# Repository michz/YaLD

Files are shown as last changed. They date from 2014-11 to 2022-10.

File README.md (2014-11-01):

YaLD - Yet another LED driver
=============================

32 channel PWM driver, controlled by a AVR microcontroller,
controllable by DMX or IR remote.

DMX data port
-------------
The RJ45 connector for DMX data follows the ANSI E1.27-2 standard:
1: DMX+
2: DMX-
3: n.c.
4: n.c.
5: n.c.
6: n.c.
7: GND
8: GND

(This port *is not* compatible to Traxon/e:cue DMX interfaces.)

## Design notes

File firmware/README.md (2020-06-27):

YaLD firmware
=============

Simple UART Algorithm
---------------------

Similar to dmx. but with 8n1 and 19200 baud.

Break (framing error) indicates start of sequence, then 32 bytes of data follow.

Attribution
-----------

### DMX Receiver

The DMX receiver part is based on the awesome work of Hendrik Hölscher.

* Original link: http://www.hoelscher-hi.de/hendrik/light/ressources.htm
* Webarchive link: http://web.archive.org/web/20190205212024/http://www.hoelscher-hi.de/hendrik/light/ressources.htm

### I2C master library

The I2C (also known as TWI) master library is written by Peter Fleury.

* Original link: http://homepage.hispeed.ch/peterfleury/avr-software.html
* Webarchive link: http://web.archive.org/web/20190621180729/http://homepage.hispeed.ch/peterfleury/avr-software.html

### FastLED Library for LED driving and effects

From http://fastled.io/ .

### millis Library for tracking milliseconds

By Zak Kemble.

Source: https://github.com/zkemble/millis

### Software-UART for debugging (RX only)

Source: https://rn-wissen.de/wiki/index.php/Software-UART_mit_avr-gcc

### IRMP Multi protocol IR receiver library

Source: https://www.mikrocontroller.net/articles/IRMP

License
-------

* DMX Receiver part: GPL (no version given, see http://web.archive.org/web/20161109091517/http://www.hoelscher-hi.de/hendrik/light/ressources/an012.pdf )
* I2C library: GPL Version 3
* FastLED: MIT
* millis library: GPL Version 3
* IRMP: GPL Version 2
* Other parts of the firmware: GPL Version 3
  (especially all files authored by "Michael Zapf")

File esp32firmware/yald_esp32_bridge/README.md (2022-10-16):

# YaLD esp32 MQTT bridge

## Build

Recommendation: Through PlatformIO extension in vscode.

## Deploy

Either "PlatformIO: Upload" in vscode.

Or:

```
curl -v -XPOST -F "upload=@.pio/build/wemos_d1_mini32/firmware.bin" http://192.168.0.119/update
```

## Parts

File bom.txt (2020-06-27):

Bill of Materials
=================

(not marked on board)

X1      16MHz
C3      4,7uF
C4      330n

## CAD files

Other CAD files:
firmware/dmx/ASM/Assembler.obj

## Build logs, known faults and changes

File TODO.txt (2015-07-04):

PCB: Ausgänge beschriften (VCC, PWM0, PWM1, PWM2, ...)

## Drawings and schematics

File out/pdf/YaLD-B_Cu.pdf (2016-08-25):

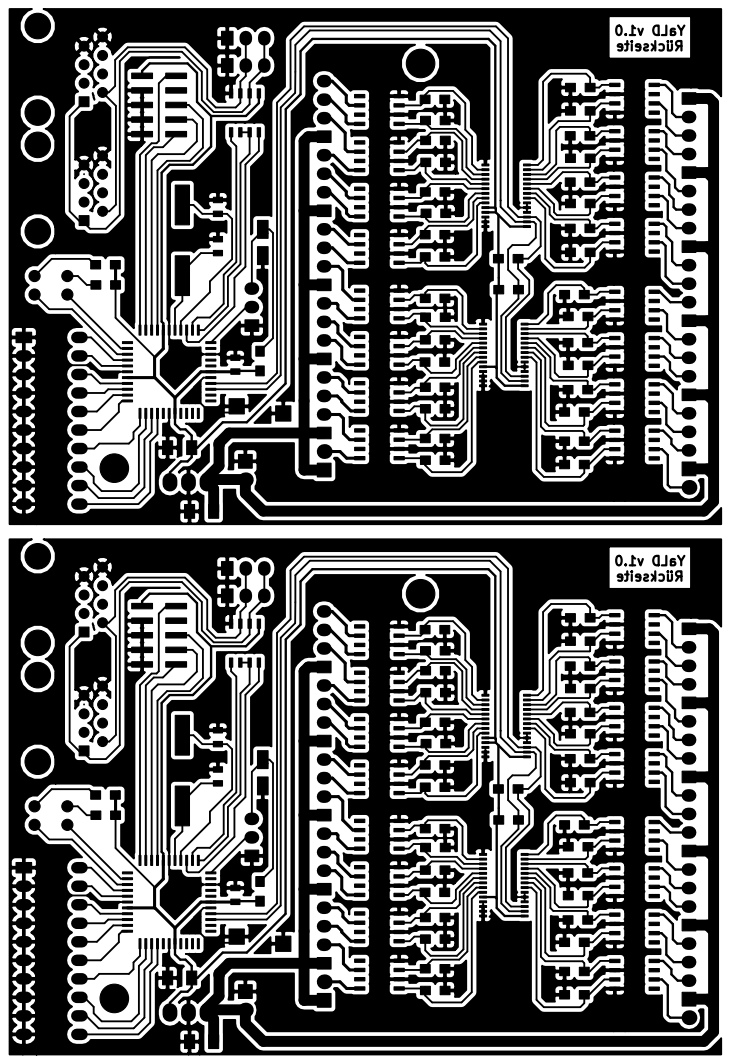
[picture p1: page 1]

YaLD v1.0 Rückseite

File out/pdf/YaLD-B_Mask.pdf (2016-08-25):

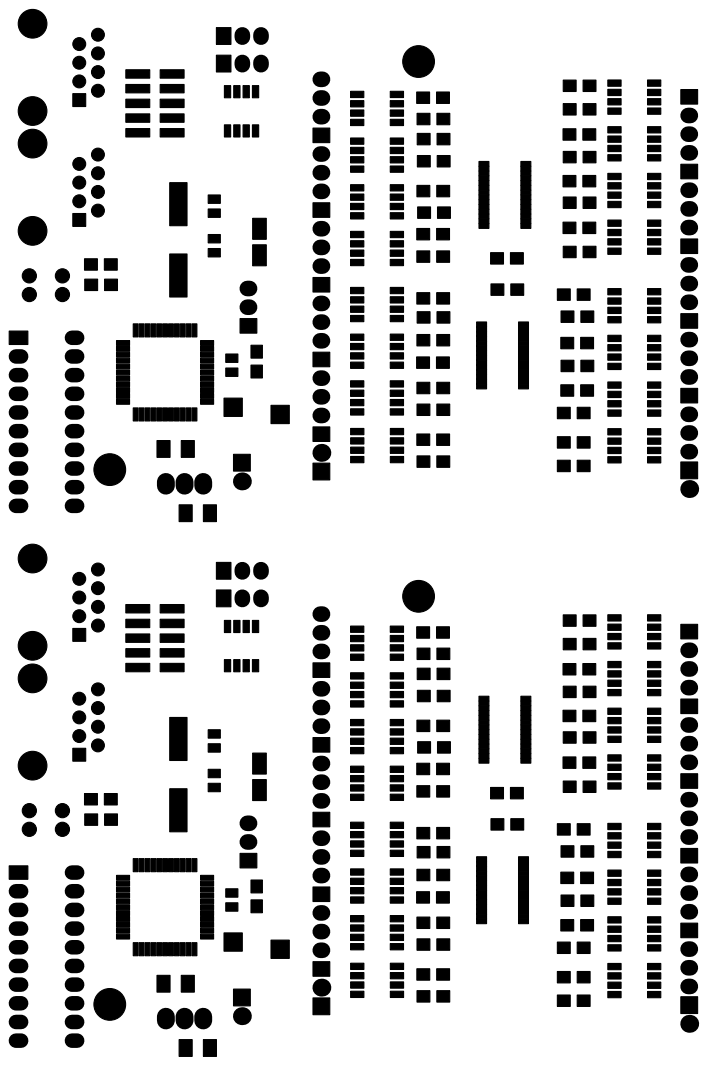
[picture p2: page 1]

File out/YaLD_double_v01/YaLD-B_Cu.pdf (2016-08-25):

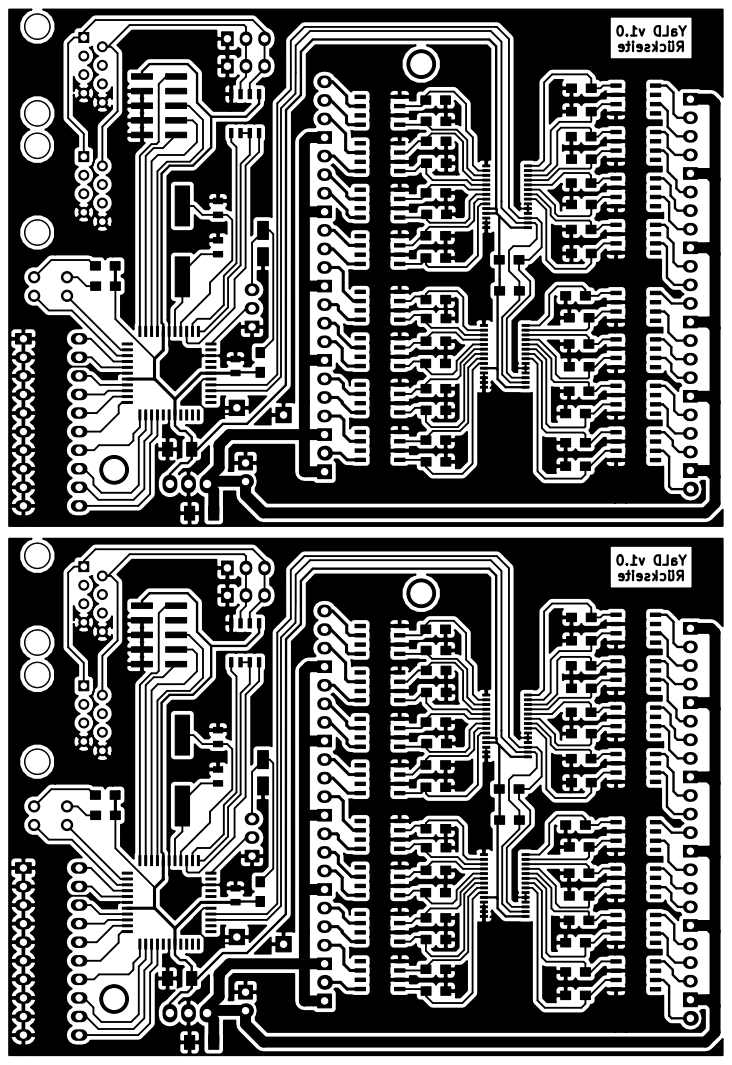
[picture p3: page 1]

YaLD v1.0 Rückseite

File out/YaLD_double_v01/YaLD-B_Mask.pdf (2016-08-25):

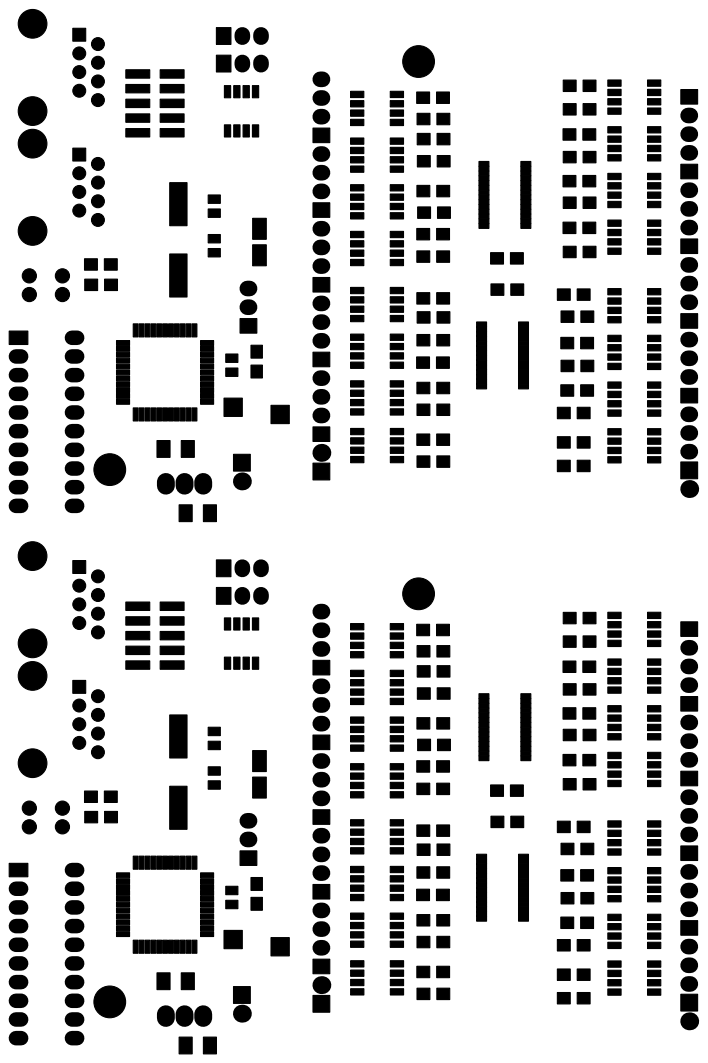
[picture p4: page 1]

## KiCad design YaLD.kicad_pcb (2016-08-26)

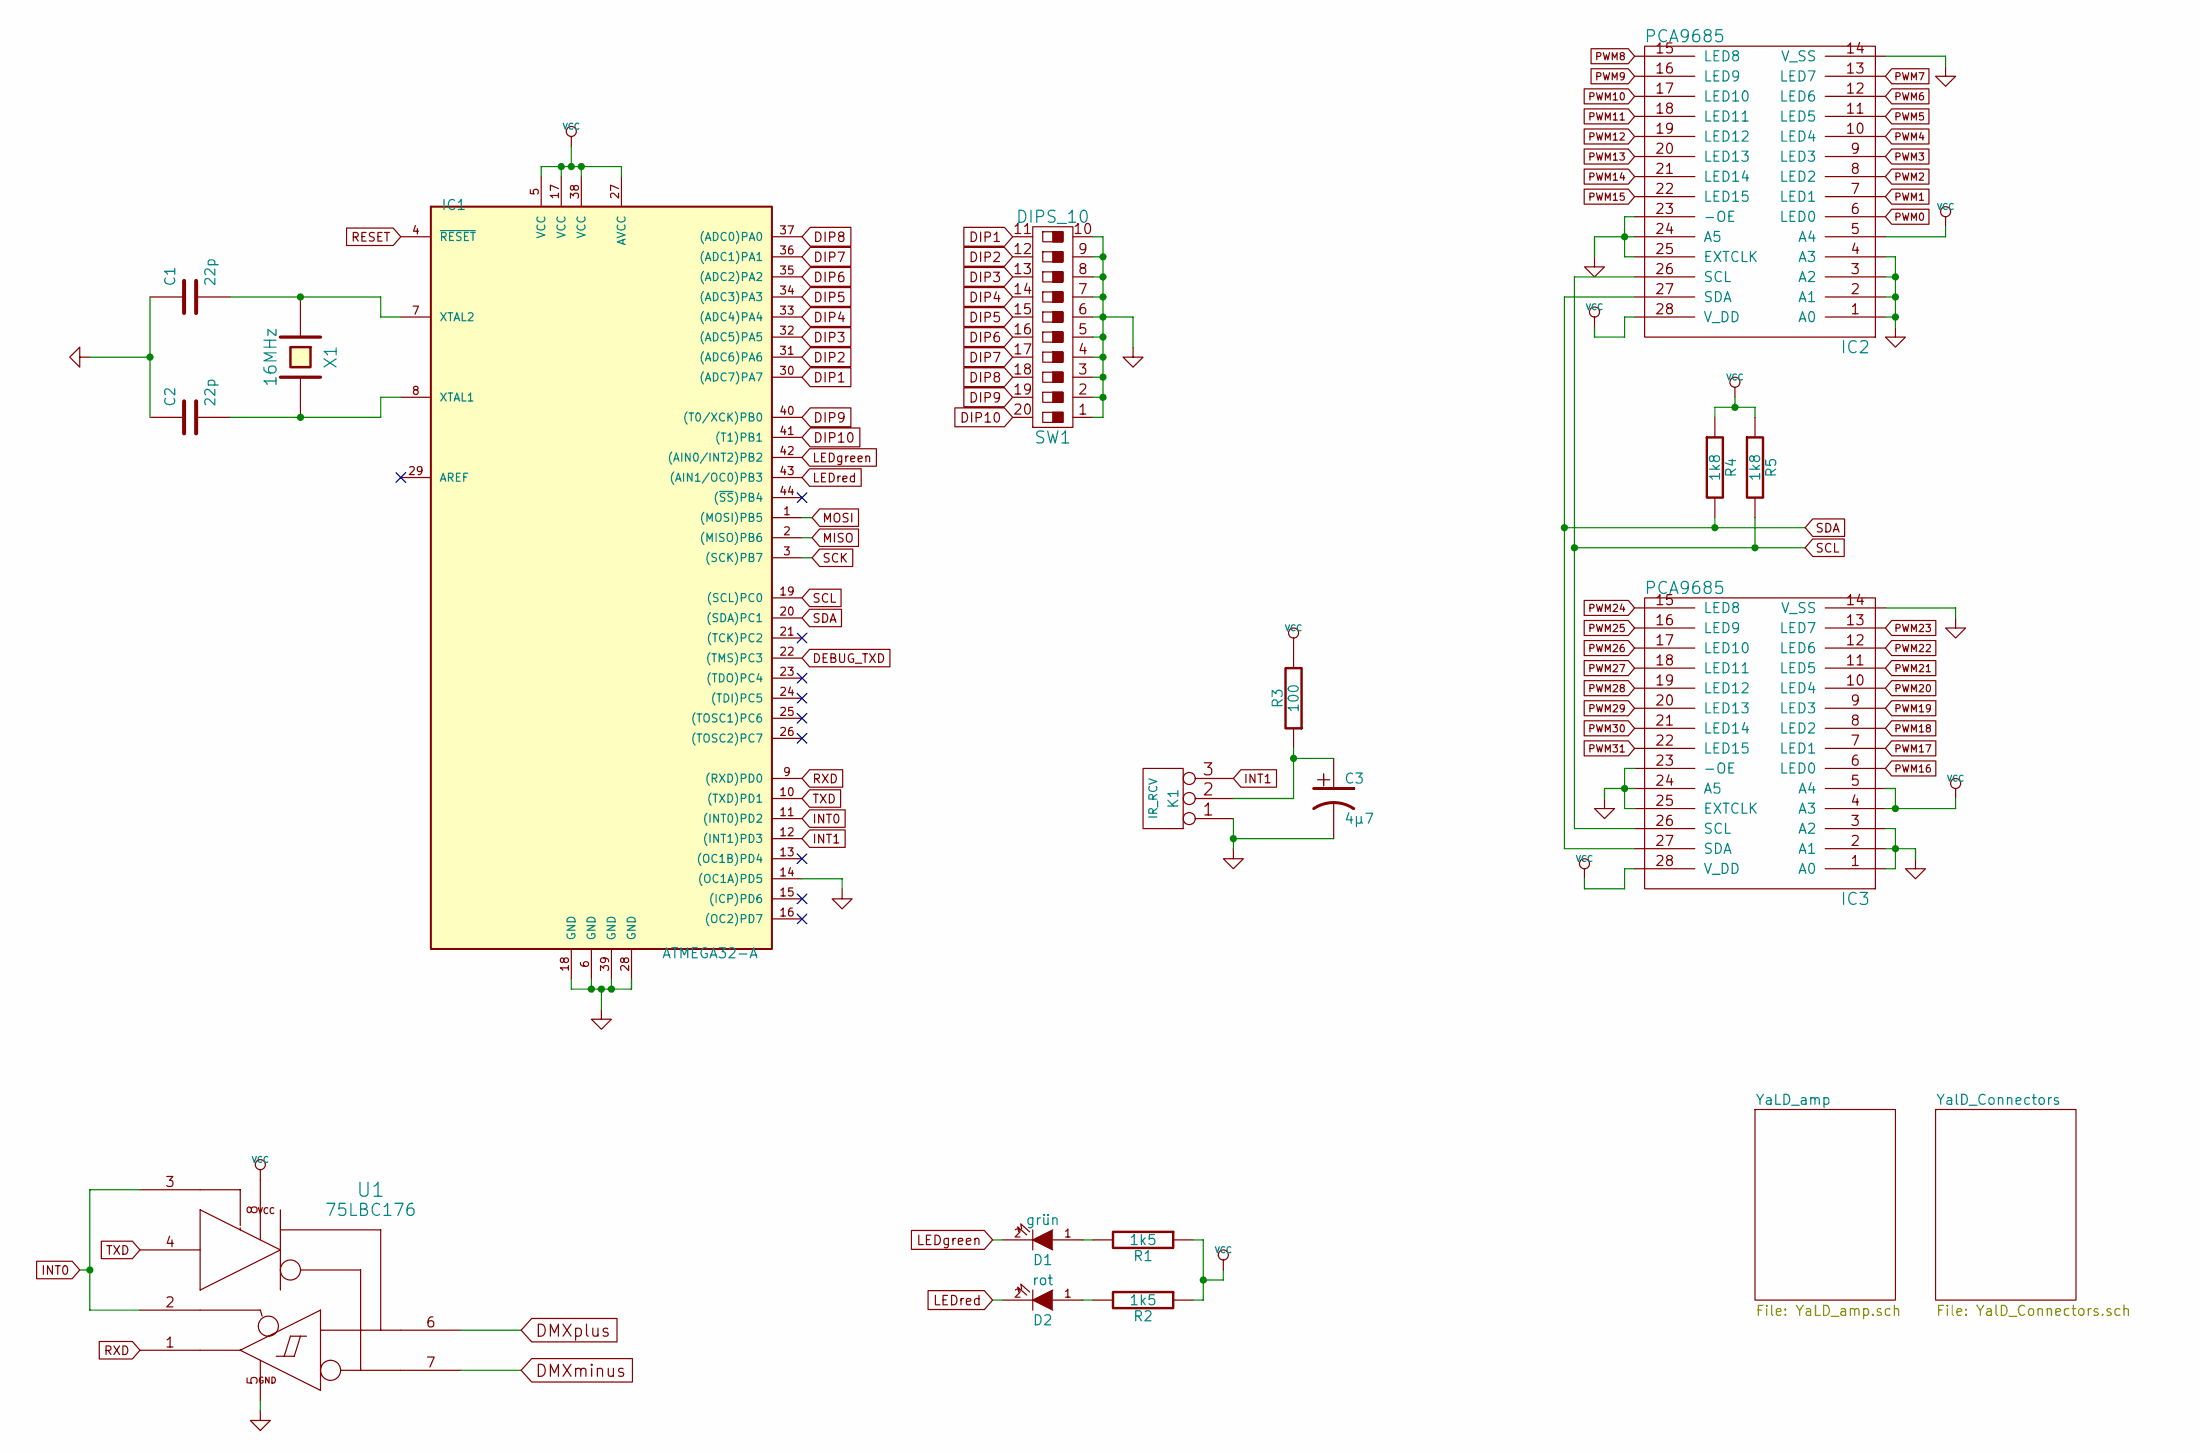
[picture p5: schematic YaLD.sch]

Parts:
C1, C2: 22p; SMD-0805
C3: 4µ7; c_elec_4x5.7
D1: grün; LED-3MM
D2: rot; LED-3MM
IC1: ATMEGA32-A; TQFP-44
IC2, IC3: PCA9685; TSSOP-28_4.4x9.7mm_Pitch0.65mm
K1: IR_RCV; Pin_Header_Straight_1x03
R1, R2: 1k5; R_0805_HandSoldering
R3: 100; R_0805_HandSoldering
R4, R5: 1k8; R_0805_HandSoldering
SW1: DIPS_10; DIP-20__300_ELL
U1: 75LBC176; SOIC-8-W
X1: 16MHz; Crystal_HC49-SD_SMD

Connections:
DEBUG_TXD: IC1.22 ((TMS)PC3); also elsewhere on the board
DIP1: IC1.30 ((ADC7)PA7), SW1.11
DIP2: IC1.31 ((ADC6)PA6), SW1.12
DIP3: IC1.32 ((ADC5)PA5), SW1.13
DIP4: IC1.33 ((ADC4)PA4), SW1.14
DIP5: IC1.34 ((ADC3)PA3), SW1.15
DIP6: IC1.35 ((ADC2)PA2), SW1.16
DIP7: IC1.36 ((ADC1)PA1), SW1.17
DIP8: IC1.37 ((ADC0)PA0), SW1.18
DIP9: IC1.40 ((T0/XCK)PB0), SW1.19
DIP10: IC1.41 ((T1)PB1), SW1.20
DMXminus: U1.7 (BUS-); also elsewhere on the board
DMXplus: U1.6 (BUS+); also elsewhere on the board
GND: C1.1, C2.1, C3.2, IC1.6 (GND), IC1.14 ((OC1A)PD5), IC1.18 (GND), IC1.28 (GND), IC1.39 (GND), IC2.1 (A0), IC2.2 (A1), IC2.3 (A2), IC2.4 (A3), IC2.14 (V_SS), IC2.23 (-OE), IC2.24 (A5), IC2.25 (EXTCLK), IC3.1 (A0), IC3.2 (A1), IC3.3 (A2), IC3.14 (V_SS), IC3.23 (-OE), IC3.24 (A5), IC3.25 (EXTCLK), K1.1, SW1.1, SW1.2, SW1.3, SW1.4, SW1.5, SW1.6, SW1.7, SW1.8, SW1.9, SW1.10, U1.5 (GND); also elsewhere on the board
INT0: IC1.11 ((INT0)PD2), U1.2 (/RE), U1.3 (DE)
INT1: IC1.12 ((INT1)PD3), K1.3
LEDgreen: D1.2 (K), IC1.42 ((AIN0/INT2)PB2)
LEDred: D2.2 (K), IC1.43 ((AIN1/OC0)PB3)
MISO: IC1.2 ((MISO)PB6); also elsewhere on the board
MOSI: IC1.1 ((MOSI)PB5); also elsewhere on the board
unnamed: C1.2, IC1.7 (XTAL2), X1.1
unnamed: C2.2, IC1.8 (XTAL1), X1.2
unnamed: C3.1, K1.2 (PM), R3.1
unnamed: D1.1 (A), R1.2
unnamed: D2.1 (A), R2.2
PWM0: IC2.6 (LED0); also elsewhere on the board
PWM1: IC2.7 (LED1); also elsewhere on the board
PWM2: IC2.8 (LED2); also elsewhere on the board
PWM3: IC2.9 (LED3); also elsewhere on the board
PWM4: IC2.10 (LED4); also elsewhere on the board
PWM5: IC2.11 (LED5); also elsewhere on the board
PWM6: IC2.12 (LED6); also elsewhere on the board
PWM7: IC2.13 (LED7); also elsewhere on the board
PWM8: IC2.15 (LED8); also elsewhere on the board
PWM9: IC2.16 (LED9); also elsewhere on the board
PWM10: IC2.17 (LED10); also elsewhere on the board
PWM11: IC2.18 (LED11); also elsewhere on the board
PWM12: IC2.19 (LED12); also elsewhere on the board
PWM13: IC2.20 (LED13); also elsewhere on the board
PWM14: IC2.21 (LED14); also elsewhere on the board
PWM15: IC2.22 (LED15); also elsewhere on the board
PWM16: IC3.6 (LED0); also elsewhere on the board
PWM17: IC3.7 (LED1); also elsewhere on the board
PWM18: IC3.8 (LED2); also elsewhere on the board
PWM19: IC3.9 (LED3); also elsewhere on the board
PWM20: IC3.10 (LED4); also elsewhere on the board
PWM21: IC3.11 (LED5); also elsewhere on the board
PWM22: IC3.12 (LED6); also elsewhere on the board
PWM23: IC3.13 (LED7); also elsewhere on the board
PWM24: IC3.15 (LED8); also elsewhere on the board
PWM25: IC3.16 (LED9); also elsewhere on the board
PWM26: IC3.17 (LED10); also elsewhere on the board
PWM27: IC3.18 (LED11); also elsewhere on the board
PWM28: IC3.19 (LED12); also elsewhere on the board
PWM29: IC3.20 (LED13); also elsewhere on the board
PWM30: IC3.21 (LED14); also elsewhere on the board
PWM31: IC3.22 (LED15); also elsewhere on the board
RESET: IC1.4 (~RESET); also elsewhere on the board
RXD: IC1.9 ((RXD)PD0), U1.1 (ROUT); also elsewhere on the board
SCK: IC1.3 ((SCK)PB7); also elsewhere on the board
SCL: IC1.19 ((SCL)PC0), IC2.26 (SCL), IC3.26 (SCL), R5.2
SDA: IC1.20 ((SDA)PC1), IC2.27 (SDA), IC3.27 (SDA), R4.2
TXD: IC1.10 ((TXD)PD1), U1.4 (DIN); also elsewhere on the board
VCC: IC1.5 (VCC), IC1.17 (VCC), IC1.27 (AVCC), IC1.38 (VCC), IC2.5 (A4), IC2.28 (V_DD), IC3.4 (A3), IC3.5 (A4), IC3.28 (V_DD), R1.1, R2.1, R3.2, R4.1, R5.1, U1.8 (VCC); also elsewhere on the board

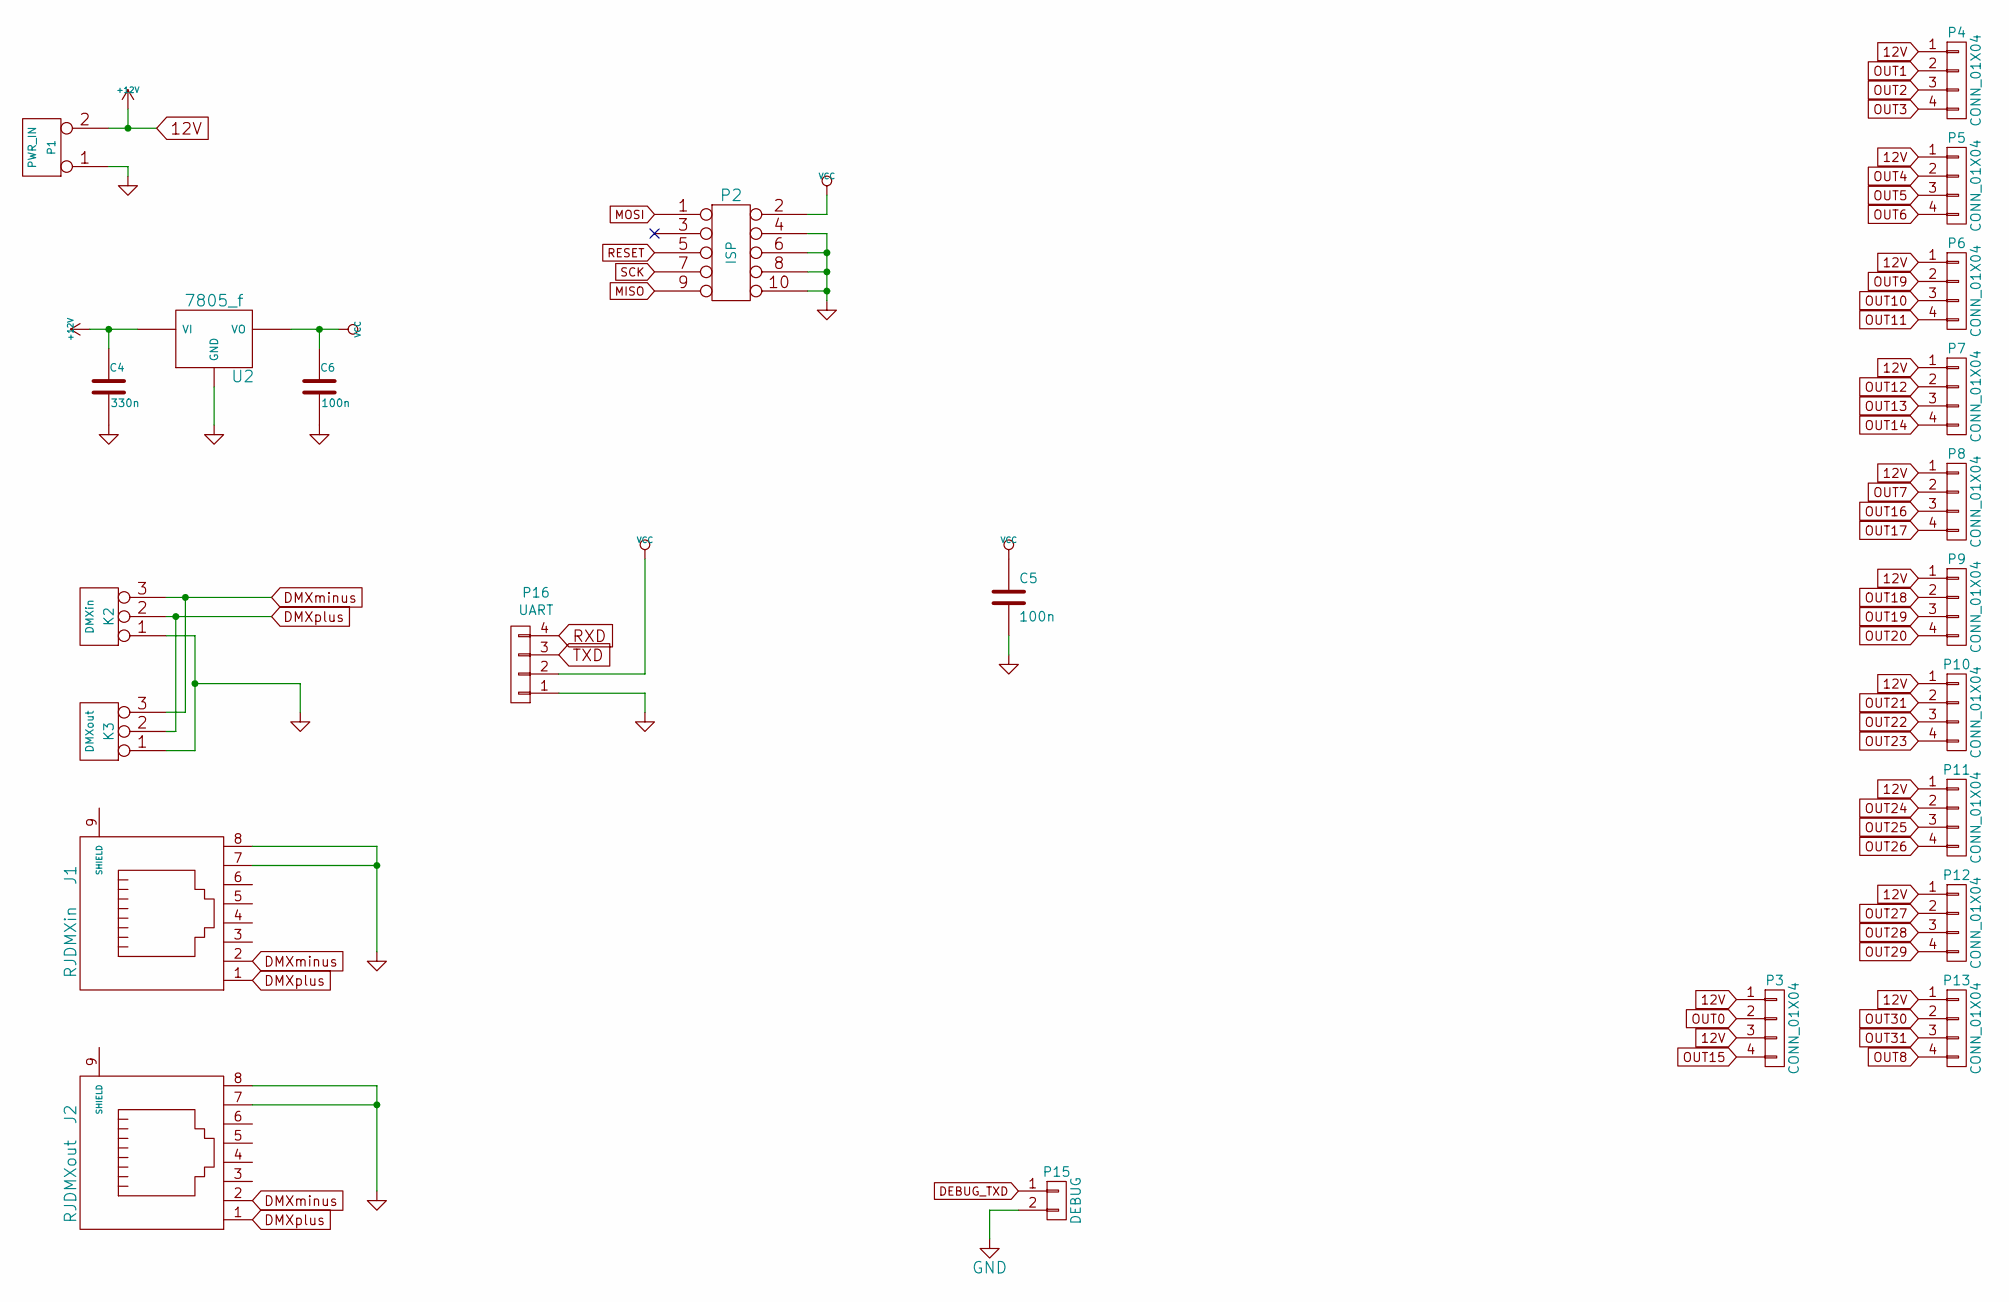
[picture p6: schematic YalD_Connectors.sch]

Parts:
C4: 330n; SMD-1206
C5: 100n; SMD-0805
C6: 100n; SMD-1206
J1: RJDMXin; RJ45_8
J2: RJDMXout; RJ45_8
K2: DMXin; Pin_Header_Straight_1x03
K3: DMXout; Pin_Header_Straight_1x03
P1: PWR_IN; Pin_Header_Straight_1x02
P2: ISP; Pin_Header_Straight_2x05
P3, P4, P5, P6, P7, P8, P9, P10, P11, P12, P13: CONN_01X04; CONN_1_4_XY350_Pitch_3.5
P15: DEBUG; Pin_Header_Straight_1x02
P16: UART; Pin_Header_Straight_1x04
U2: 7805_f; TO-220

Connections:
12V: C4.1, P1.2 (PM), P3.1, P3.3, P4.1, P5.1, P6.1, P7.1, P8.1, P9.1, P10.1, P11.1, P12.1, P13.1, U2.1 (VI)
DEBUG_TXD: P15.1; also elsewhere on the board
DMXminus: J1.2, J2.2, K2.3, K3.3; also elsewhere on the board
DMXplus: J1.1, J2.1, K2.2 (PM), K3.2 (PM); also elsewhere on the board
GND: C4.2, C5.2, C6.2, J1.7, J1.8, J2.7, J2.8, K2.1, K3.1, P1.1, P2.4, P2.6, P2.8, P2.10, P15.2, P16.1, U2.2 (GND); also elsewhere on the board
MISO: P2.9; also elsewhere on the board
MOSI: P2.1; also elsewhere on the board
OUT0: P3.2; also elsewhere on the board
OUT1: P4.2; also elsewhere on the board
OUT2: P4.3; also elsewhere on the board
OUT3: P4.4; also elsewhere on the board
OUT4: P5.2; also elsewhere on the board
OUT5: P5.3; also elsewhere on the board
OUT6: P5.4; also elsewhere on the board
OUT7: P8.2; also elsewhere on the board
OUT8: P13.4; also elsewhere on the board
OUT9: P6.2; also elsewhere on the board
OUT10: P6.3; also elsewhere on the board
OUT11: P6.4; also elsewhere on the board
OUT12: P7.2; also elsewhere on the board
OUT13: P7.3; also elsewhere on the board
OUT14: P7.4; also elsewhere on the board
OUT15: P3.4; also elsewhere on the board
OUT16: P8.3; also elsewhere on the board
OUT17: P8.4; also elsewhere on the board
OUT18: P9.2; also elsewhere on the board
OUT19: P9.3; also elsewhere on the board
OUT20: P9.4; also elsewhere on the board
OUT21: P10.2; also elsewhere on the board
OUT22: P10.3; also elsewhere on the board
OUT23: P10.4; also elsewhere on the board
OUT24: P11.2; also elsewhere on the board
OUT25: P11.3; also elsewhere on the board
OUT26: P11.4; also elsewhere on the board
OUT27: P12.2; also elsewhere on the board
OUT28: P12.3; also elsewhere on the board
OUT29: P12.4; also elsewhere on the board
OUT30: P13.2; also elsewhere on the board
OUT31: P13.3; also elsewhere on the board
RESET: P2.5; also elsewhere on the board
RXD: P16.4; also elsewhere on the board
SCK: P2.7; also elsewhere on the board
TXD: P16.3; also elsewhere on the board
VCC: C5.1, C6.1, P2.2, P16.2, U2.3 (VO); also elsewhere on the board

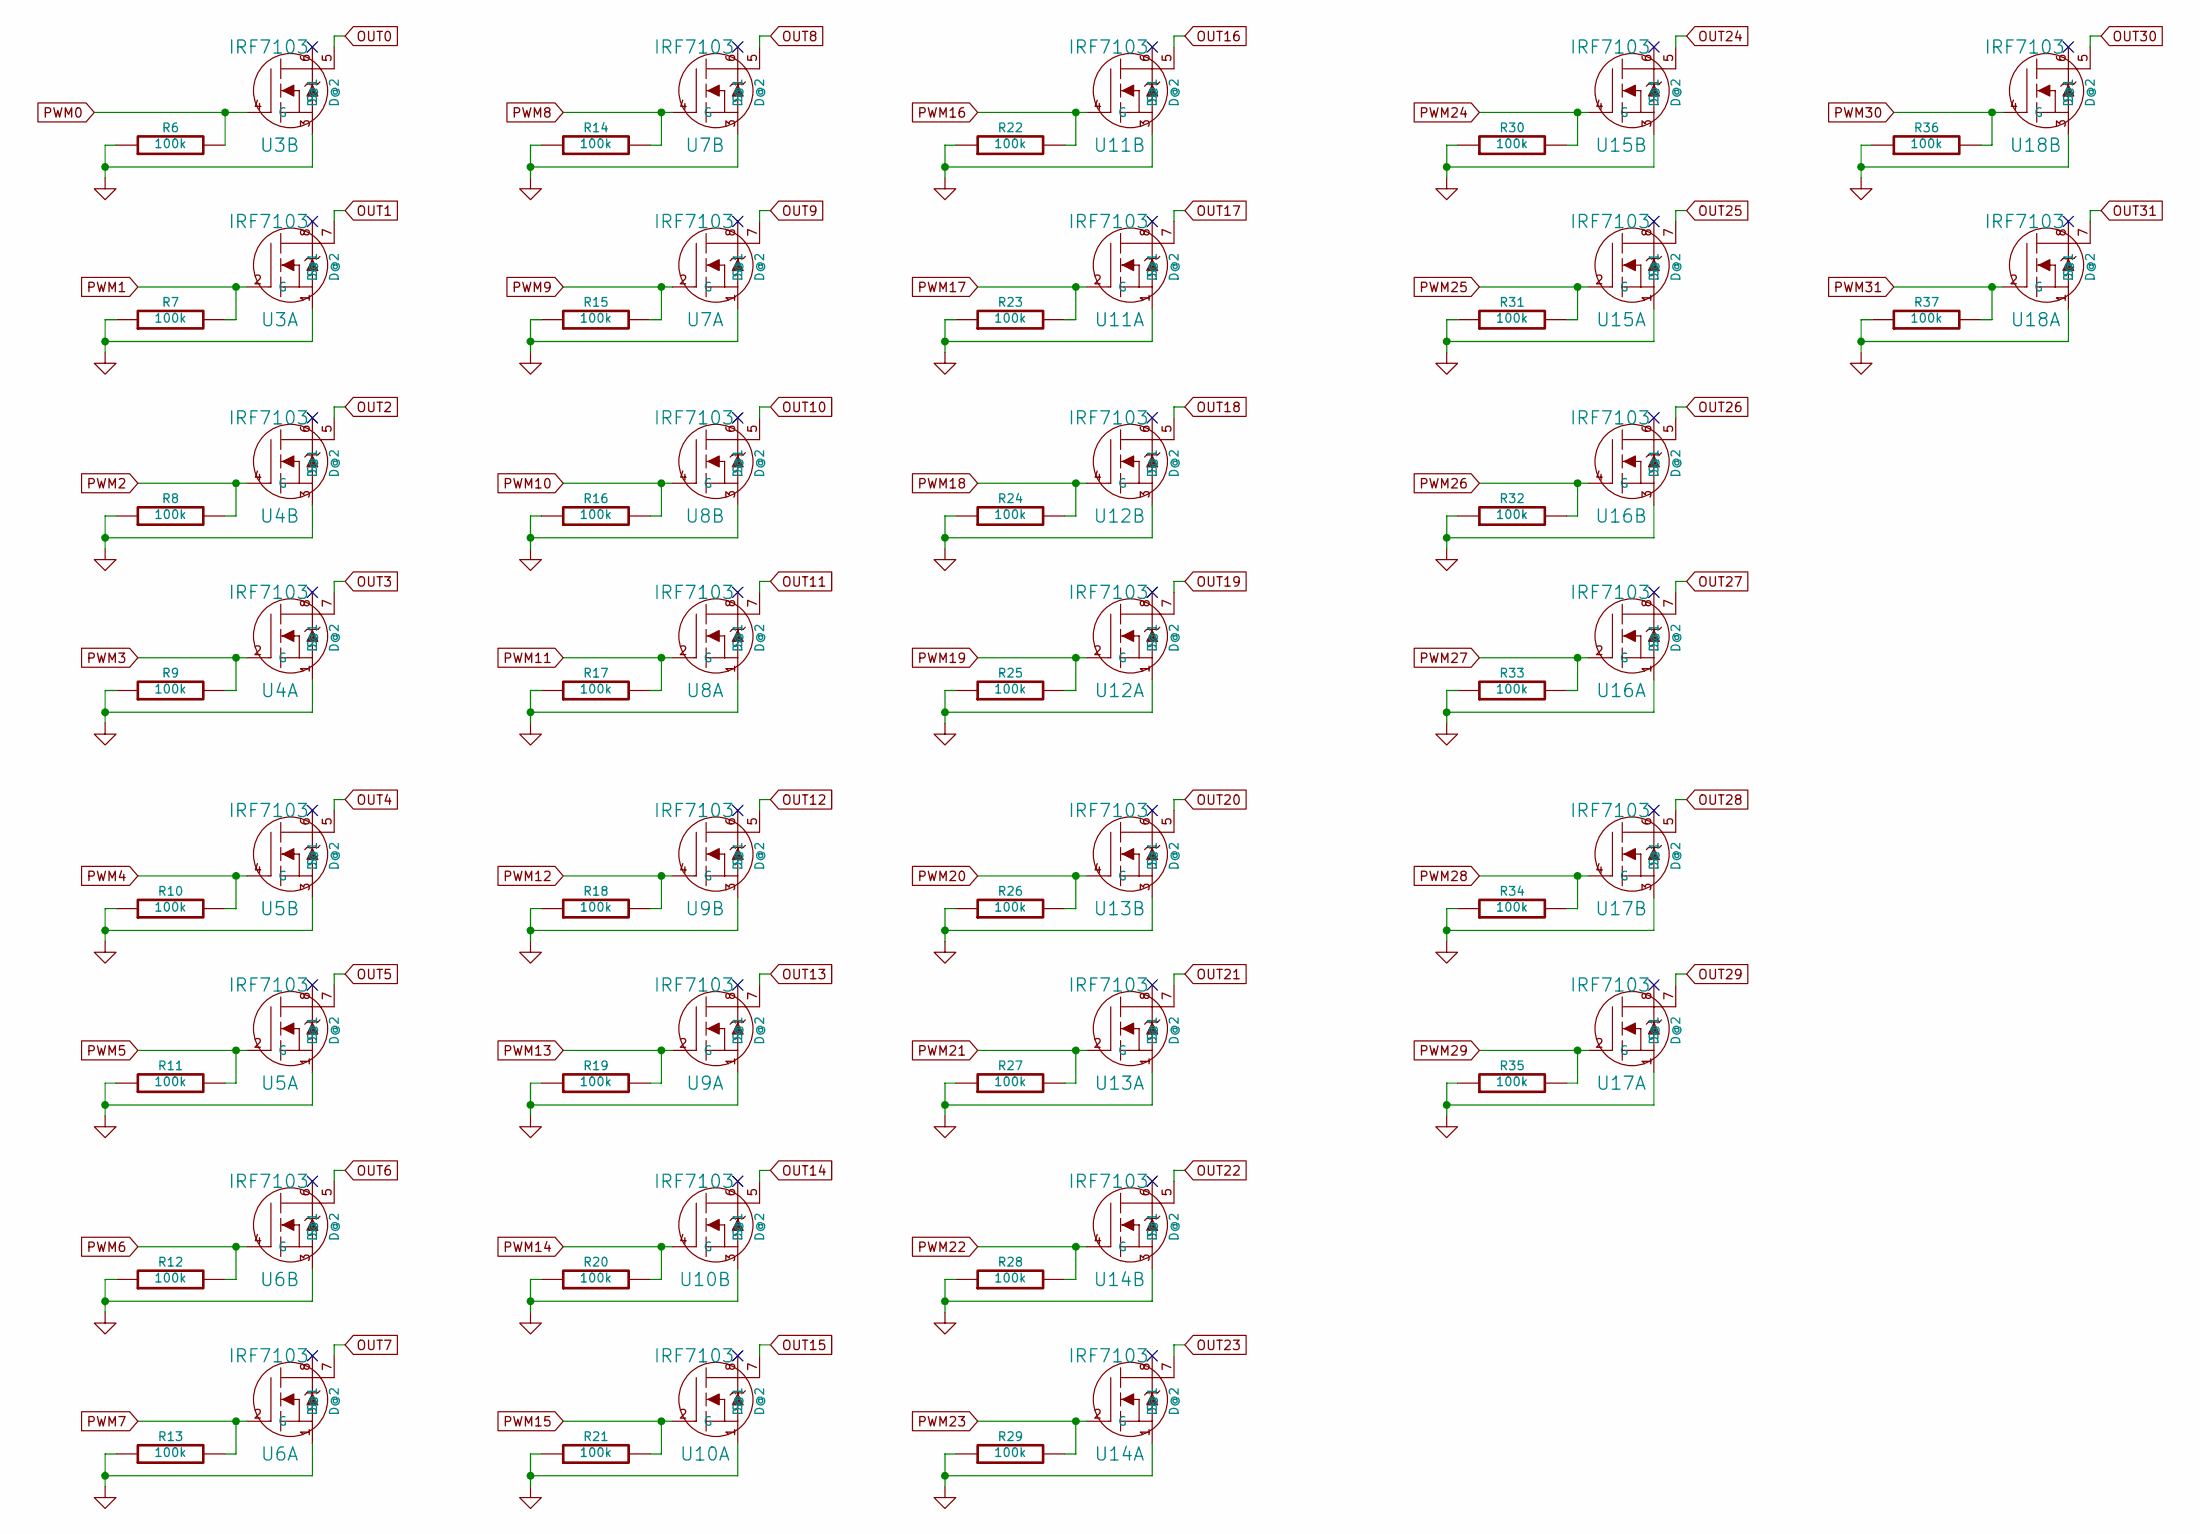
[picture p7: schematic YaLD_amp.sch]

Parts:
R6, R7, R8, R9, R10, R11, R12, R13, R14, R15, R16, R17, R18, R19, R20, R21, R22, R23, R24, R25, R26, R27, R28, R29, R30, R31, R32, R33, R34, R35, R36, R37: 100k; R_0805_HandSoldering
U3, U4, U5, U6, U7, U8, U9, U10, U11, U12, U13, U14, U15, U16, U17, U18: IRF7103; SOIC-8_3.9x4.9mm_Pitch1.27mm

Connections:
GND: R6.1, R7.1, R8.1, R9.1, R10.1, R11.1, R12.1, R13.1, R14.1, R15.1, R16.1, R17.1, R18.1, R19.1, R20.1, R21.1, R22.1, R23.1, R24.1, R25.1, R26.1, R27.1, R28.1, R29.1, R30.1, R31.1, R32.1, R33.1, R34.1, R35.1, R36.1, R37.1, U3.1 (S), U3.3 (S), U4.1 (S), U4.3 (S), U5.1 (S), U5.3 (S), U6.1 (S), U6.3 (S), U7.1 (S), U7.3 (S), U8.1 (S), U8.3 (S), U9.1 (S), U9.3 (S), U10.1 (S), U10.3 (S), U11.1 (S), U11.3 (S), U12.1 (S), U12.3 (S), U13.1 (S), U13.3 (S), U14.1 (S), U14.3 (S), U15.1 (S), U15.3 (S), U16.1 (S), U16.3 (S), U17.1 (S), U17.3 (S), U18.1 (S), U18.3 (S); also elsewhere on the board
OUT0: U3.5 (D@2); also elsewhere on the board
OUT1: U3.7 (D@2); also elsewhere on the board
OUT2: U4.5 (D@2); also elsewhere on the board
OUT3: U4.7 (D@2); also elsewhere on the board
OUT4: U5.5 (D@2); also elsewhere on the board
OUT5: U5.7 (D@2); also elsewhere on the board
OUT6: U6.5 (D@2); also elsewhere on the board
OUT7: U6.7 (D@2); also elsewhere on the board
OUT8: U7.5 (D@2); also elsewhere on the board
OUT9: U7.7 (D@2); also elsewhere on the board
OUT10: U8.5 (D@2); also elsewhere on the board
OUT11: U8.7 (D@2); also elsewhere on the board
OUT12: U9.5 (D@2); also elsewhere on the board
OUT13: U9.7 (D@2); also elsewhere on the board
OUT14: U10.5 (D@2); also elsewhere on the board
OUT15: U10.7 (D@2); also elsewhere on the board
OUT16: U11.5 (D@2); also elsewhere on the board
OUT17: U11.7 (D@2); also elsewhere on the board
OUT18: U12.5 (D@2); also elsewhere on the board
OUT19: U12.7 (D@2); also elsewhere on the board
OUT20: U13.5 (D@2); also elsewhere on the board
OUT21: U13.7 (D@2); also elsewhere on the board
OUT22: U14.5 (D@2); also elsewhere on the board
OUT23: U14.7 (D@2); also elsewhere on the board
OUT24: U15.5 (D@2); also elsewhere on the board
OUT25: U15.7 (D@2); also elsewhere on the board
OUT26: U16.5 (D@2); also elsewhere on the board
OUT27: U16.7 (D@2); also elsewhere on the board
OUT28: U17.5 (D@2); also elsewhere on the board
OUT29: U17.7 (D@2); also elsewhere on the board
OUT30: U18.5 (D@2); also elsewhere on the board
OUT31: U18.7 (D@2); also elsewhere on the board
PWM0: R6.2, U3.4 (G); also elsewhere on the board
PWM1: R7.2, U3.2 (G); also elsewhere on the board
PWM2: R8.2, U4.4 (G); also elsewhere on the board
PWM3: R9.2, U4.2 (G); also elsewhere on the board
PWM4: R10.2, U5.4 (G); also elsewhere on the board
PWM5: R11.2, U5.2 (G); also elsewhere on the board
PWM6: R12.2, U6.4 (G); also elsewhere on the board
PWM7: R13.2, U6.2 (G); also elsewhere on the board
PWM8: R14.2, U7.4 (G); also elsewhere on the board
PWM9: R15.2, U7.2 (G); also elsewhere on the board
PWM10: R16.2, U8.4 (G); also elsewhere on the board
PWM11: R17.2, U8.2 (G); also elsewhere on the board
PWM12: R18.2, U9.4 (G); also elsewhere on the board
PWM13: R19.2, U9.2 (G); also elsewhere on the board
PWM14: R20.2, U10.4 (G); also elsewhere on the board
PWM15: R21.2, U10.2 (G); also elsewhere on the board
PWM16: R22.2, U11.4 (G); also elsewhere on the board
PWM17: R23.2, U11.2 (G); also elsewhere on the board
PWM18: R24.2, U12.4 (G); also elsewhere on the board
PWM19: R25.2, U12.2 (G); also elsewhere on the board
PWM20: R26.2, U13.4 (G); also elsewhere on the board
PWM21: R27.2, U13.2 (G); also elsewhere on the board
PWM22: R28.2, U14.4 (G); also elsewhere on the board
PWM23: R29.2, U14.2 (G); also elsewhere on the board
PWM24: R30.2, U15.4 (G); also elsewhere on the board
PWM25: R31.2, U15.2 (G); also elsewhere on the board
PWM26: R32.2, U16.4 (G); also elsewhere on the board
PWM27: R33.2, U16.2 (G); also elsewhere on the board
PWM28: R34.2, U17.4 (G); also elsewhere on the board
PWM29: R35.2, U17.2 (G); also elsewhere on the board
PWM30: R36.2, U18.4 (G); also elsewhere on the board
PWM31: R37.2, U18.2 (G); also elsewhere on the board

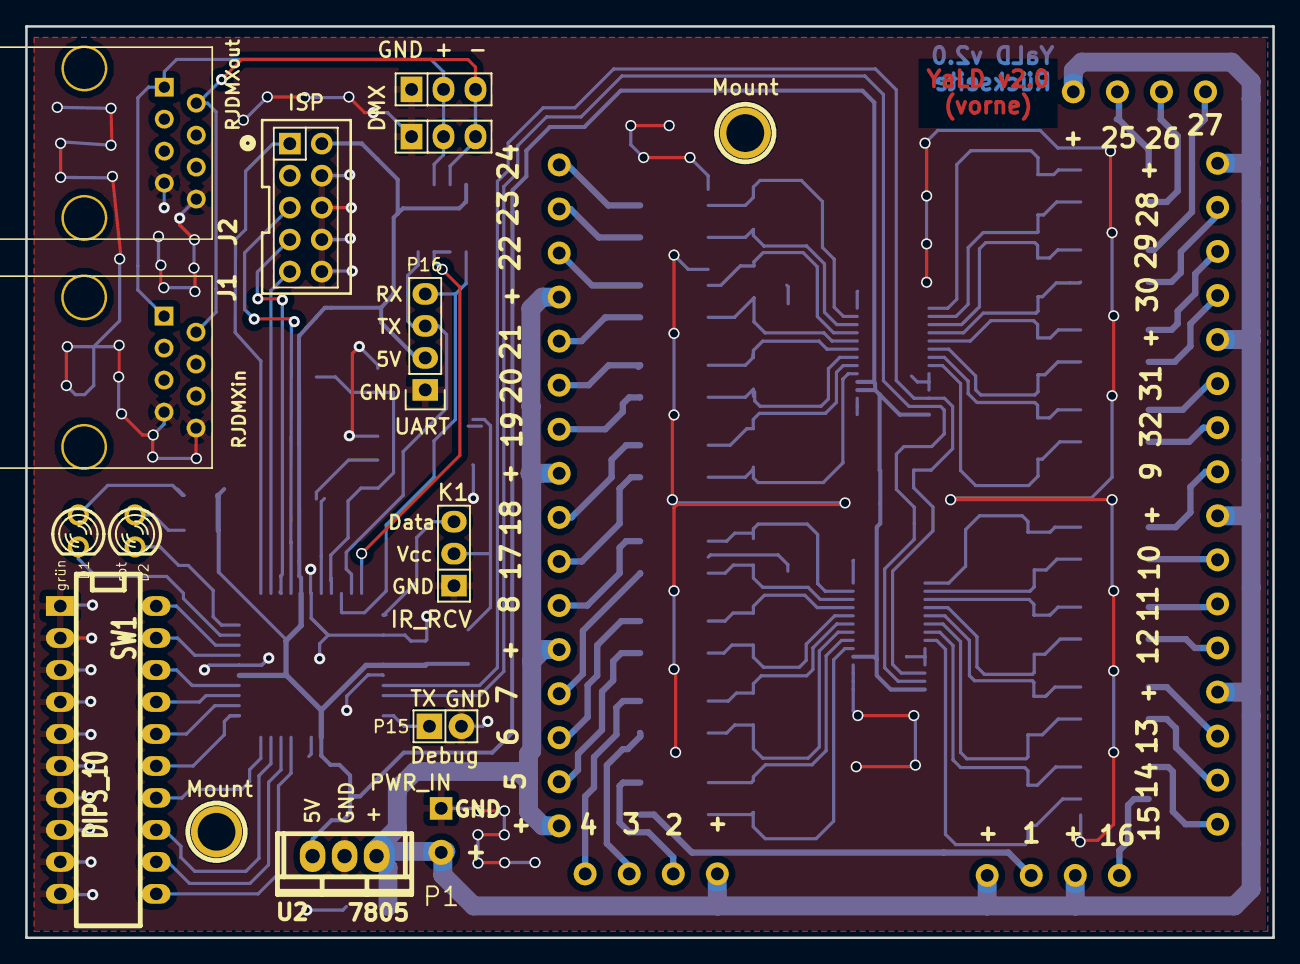
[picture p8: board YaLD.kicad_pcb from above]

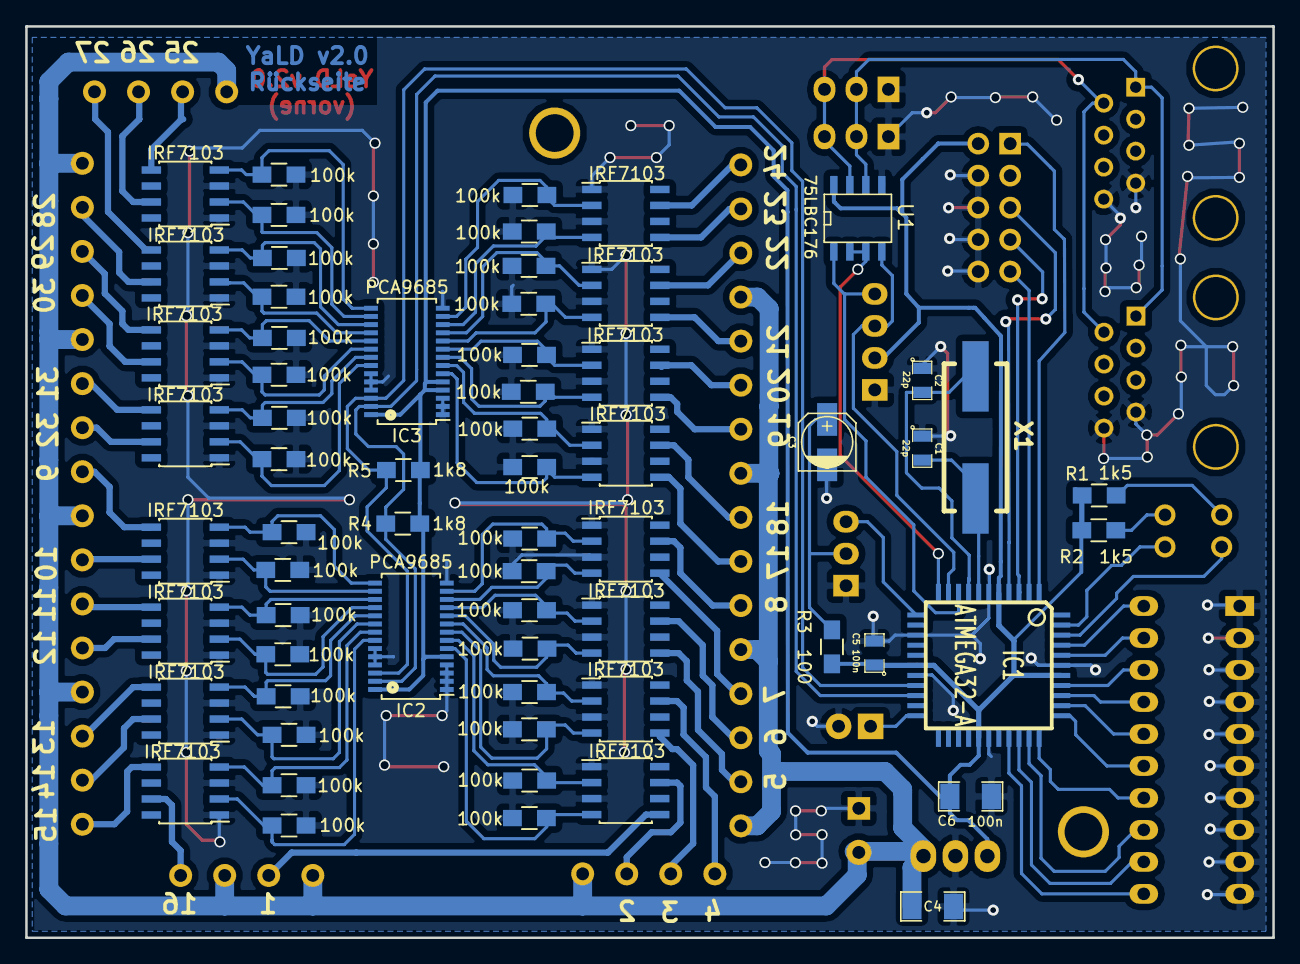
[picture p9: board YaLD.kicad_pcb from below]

Board: 2 copper layers, 99.1 x 72.4 mm, 90 parts (64 on the bottom side), 97 nets.

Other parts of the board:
1PIN, 1PIN#2: P***; 1pin

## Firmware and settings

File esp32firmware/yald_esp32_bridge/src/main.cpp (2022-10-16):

#include "main.h"

#define CHANNEL_COUNT 32

WiFiClient espClient;
uint8_t data[CHANNEL_COUNT];

/*
Topics:

/yald/1/rgb/1/set {r: 255, g: 0, b: 255}
/yald/1/channel/8/set 255

/yald/1/rgb/+/set {r: r, g: g, b: b}
/yald/1/channel/+/set value
*/

#define MQTT_TOPIC_BASE                     "/yald/"
#define MQTT_TOPIC_WILDCARD_SINGLE          "+"
#define MQTT_TOPIC_FORMAT_SINGLE            "%d"
#define MQTT_TOPIC_CHANNEL                  "/channel/"
#define MQTT_TOPIC_RGB                      "/rgb/"
#define MQTT_TOPIC_SET_SUFFIX               "/set"
#define MQTT_TOPIC_FIRMWARE_VERSION_SUFFIX  "/_firmware/version"
#define MQTT_TOPIC_MY_IP_SUFFIX             "/_my_ip"

#define MQTT_TOPIC_SET_RGB                  MQTT_TOPIC_BASE MZTX_DEVICE_ID MQTT_TOPIC_RGB MQTT_TOPIC_WILDCARD_SINGLE MQTT_TOPIC_SET_SUFFIX
#define MQTT_TOPIC_SET_CHANNEL              MQTT_TOPIC_BASE MZTX_DEVICE_ID MQTT_TOPIC_CHANNEL MQTT_TOPIC_WILDCARD_SINGLE MQTT_TOPIC_SET_SUFFIX
#define MQTT_TOPIC_FORMAT_SET_RGB           MQTT_TOPIC_BASE MZTX_DEVICE_ID MQTT_TOPIC_RGB MQTT_TOPIC_FORMAT_SINGLE MQTT_TOPIC_SET_SUFFIX
#define MQTT_TOPIC_FORMAT_SET_CHANNEL       MQTT_TOPIC_BASE MZTX_DEVICE_ID MQTT_TOPIC_CHANNEL MQTT_TOPIC_FORMAT_SINGLE MQTT_TOPIC_SET_SUFFIX
#define MQTT_TOPIC_FIRMWARE_VERSION         MQTT_TOPIC_BASE MZTX_DEVICE_ID MQTT_TOPIC_FIRMWARE_VERSION_SUFFIX
#define MQTT_TOPIC_MY_IP                    MQTT_TOPIC_BASE MZTX_DEVICE_ID MQTT_TOPIC_MY_IP_SUFFIX

void setup() {
    MZTX_DEBUG_INIT();

    // Init serial interface to LED processor
    Serial2.begin(38400, SERIAL_8N1);
    //Serial2.begin(19200, SERIAL_8N1, 12, 13);

    //WiFi.begin(WIFI_SSID, WIFI_KEY);

    // Init WIFI communication
    WiFi.persistent(false);             // Prevent flash corruption
    WiFi.setHostname(WIFI_HOSTNAME);

    WiFi.mode(WIFI_STA);
    WiFi.disconnect();
    delay(100);
    WiFi.begin(WIFI_SSID, WIFI_KEY);

    while (WiFi.status() != WL_CONNECTED) {
        if (WiFi.status() == WL_CONNECT_FAILED) {
            //gotoSleep();
            MZTX_DEBUG_PRINTLN("WiFi setup failed. Waiting for 1s...");
            delay(1000);
        }

        MZTX_DEBUG_PRINTLN("WiFi not connected yet. Waiting for 250ms...");
        delay(250);
    }

    // Initialize data array (should be done automatically, but for sure...)
    memset(data, CHANNEL_COUNT, CHANNEL_COUNT * sizeof(uint8_t));

   initUpdateServer();

    mqttInit();
    mqttReconnect();

    mqttSubscribe(MQTT_TOPIC_SET_RGB);
    mqttSubscribe(MQTT_TOPIC_SET_CHANNEL);

    mqttLoop();
    mqttPublish(MQTT_TOPIC_FIRMWARE_VERSION, MZTX_FIRMWARE_VERSION, true);
    mqttPublish(MQTT_TOPIC_MY_IP, WiFi.localIP().toString().c_str(), true);
}

inline void SendBreak()
{
    Serial2.updateBaudRate(9600);
    uint8_t buf[] = {0};
    Serial2.write(buf, sizeof(buf));
    Serial2.flush();
    Serial2.updateBaudRate(38400);
}

void loop() {
    // break
    SendBreak();

    //Serial2.write(data, 32);
    Serial2.write(data, CHANNEL_COUNT);
    Serial2.flush();

    loopUpdateServer();

    if (false == mqttConnected()) {
        mqttReconnect();
    }

    mqttLoop();
}

void mqttCallback(char* topic, byte* payload, unsigned int length)
{
    int channel = 0;
    if (1 == sscanf(topic, MQTT_TOPIC_FORMAT_SET_RGB, &channel)) {
        MZTX_DEBUG_PRINTLN("RGB line");

        const int capacity = JSON_OBJECT_SIZE(12*4);
        StaticJsonDocument<capacity> doc;
        DeserializationError err = deserializeJson(doc, payload, length);

        if (err) {
            return;
        }

        data[channel-1] = (uint8_t) (doc["r"]);
        data[channel] = (uint8_t) (doc["g"]);
        data[channel+1] = (uint8_t) (doc["b"]);
    } else if (1 == sscanf(topic, MQTT_TOPIC_FORMAT_SET_CHANNEL, &channel)) {
        // Add missing terminating null byte to payload
        payload[length] = '\0';

        int valueInt = atoi((const char *) payload);
        uint8_t value = valueInt & 0xFF;
        data[channel-1] = value;

        MZTX_DEBUG_PRINTLN("Channel line");
        MZTX_DEBUG_PRINTLN(channel);
        MZTX_DEBUG_PRINTLN(value);
    }
}

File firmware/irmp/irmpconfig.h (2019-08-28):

/*---------------------------------------------------------------------------------------------------------------------------------------------------
 * irmpconfig.h
 *
 * DO NOT INCLUDE THIS FILE, WILL BE INCLUDED BY IRMP.H!
 *
 * Copyright (c) 2009-2014 Frank Meyer - frank(at)fli4l.de
 * Extensions for PIC 12F1820 W.Strobl 2014-07-20
 *
 * $Id: irmpconfig.h,v 1.121 2014/09/15 12:36:28 fm Exp $
 *
 * This program is free software; you can redistribute it and/or modify
 * it under the terms of the GNU General Public License as published by
 * the Free Software Foundation; either version 2 of the License, or
 * (at your option) any later version.
 *---------------------------------------------------------------------------------------------------------------------------------------------------
 */

#ifndef _IRMPCONFIG_H_
#define _IRMPCONFIG_H_

#ifndef _IRMP_H_
#  error please include only irmp.h, not irmpconfig.h
#endif

/*---------------------------------------------------------------------------------------------------------------------------------------------------
 * Change F_INTERRUPTS if you change the number of interrupts per second,
 * Normally, F_INTERRUPTS should be in the range from 10000 to 15000, typical is 15000
 * A value above 15000 costs additional program space, absolute maximum value is 20000.
 * On PIC with XC8/C18 Compiler, use 15151 as the correct value.
 *---------------------------------------------------------------------------------------------------------------------------------------------------
 */
#ifndef F_INTERRUPTS
#  define F_INTERRUPTS                          15000   // interrupts per second, min: 10000, max: 20000, typ: 15000
#endif

/*---------------------------------------------------------------------------------------------------------------------------------------------------
 * Change settings from 1 to 0 if you want to disable one or more decoders.
 * This saves program space.
 *
 * 1 enable  decoder
 * 0 disable decoder
 *
 * The standard decoders are enabled per default.
 * Less common protocols are disabled here, you need to enable them manually.
 *
 * If you want to use FDC or RCCAR simultaneous with RC5 protocol, additional program space is required.
 * If you don't need RC5 when using FDC/RCCAR, you should disable RC5.
 * You cannot enable both DENON and RUWIDO, only enable one of them.
 *---------------------------------------------------------------------------------------------------------------------------------------------------
 */

// typical protocols, disable here!             Enable  Remarks                 F_INTERRUPTS            Program Space
#define IRMP_SUPPORT_SIRCS_PROTOCOL             1       // Sony SIRCS           >= 10000                 ~150 bytes
#define IRMP_SUPPORT_NEC_PROTOCOL               1       // NEC + APPLE          >= 10000                 ~300 bytes
#define IRMP_SUPPORT_SAMSUNG_PROTOCOL           0       // Samsung + Samsg32    >= 10000                 ~300 bytes
#define IRMP_SUPPORT_KASEIKYO_PROTOCOL          0       // Kaseikyo             >= 10000                 ~250 bytes

// more protocols, enable here!                 Enable  Remarks                 F_INTERRUPTS            Program Space
#define IRMP_SUPPORT_JVC_PROTOCOL               0       // JVC                  >= 10000                 ~150 bytes
#define IRMP_SUPPORT_NEC16_PROTOCOL             1       // NEC16                >= 10000                 ~100 bytes
#define IRMP_SUPPORT_NEC42_PROTOCOL             0       // NEC42                >= 10000                 ~300 bytes
#define IRMP_SUPPORT_MATSUSHITA_PROTOCOL        0       // Matsushita           >= 10000                  ~50 bytes
#define IRMP_SUPPORT_DENON_PROTOCOL             0       // DENON, Sharp         >= 10000                 ~250 bytes
#define IRMP_SUPPORT_RC5_PROTOCOL               1       // RC5                  >= 10000                 ~250 bytes
#define IRMP_SUPPORT_RC6_PROTOCOL               1       // RC6 & RC6A           >= 10000                 ~250 bytes
#define IRMP_SUPPORT_IR60_PROTOCOL              0       // IR60 (SDA2008)       >= 10000                 ~300 bytes
#define IRMP_SUPPORT_GRUNDIG_PROTOCOL           0       // Grundig              >= 10000                 ~300 bytes
#define IRMP_SUPPORT_SIEMENS_PROTOCOL           0       // Siemens Gigaset      >= 15000                 ~550 bytes
#define IRMP_SUPPORT_NOKIA_PROTOCOL             0       // Nokia                >= 10000                 ~300 bytes
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

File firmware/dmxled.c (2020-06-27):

#include <avr/interrupt.h>
#include <avr/io.h>
#include <avr/wdt.h>
#include <util/delay.h>

#include "dmxled.h"
#include "pwmout.h"
#include "led.h"

#ifndef TARGET_UART_SIMPLE
#include "irmp/irmp.h"
#include "ir_mode.h"
#include "dmx/C/lib_dmx_in.h"
#else
#include "uart_simple.h"
#endif

#ifdef DEBUG
#include "suart.h"
#endif

#ifdef __cplusplus
extern "C" {
#endif

volatile uint8_t gGlobalState;
volatile uint32_t dmxIdleTicks = 0;

static inline void initDIPs(void);

#ifndef TARGET_UART_SIMPLE
int main(void) {
    wdt_disable();                  // disable watchdog for boot
    gGlobalState = INIT;
    cli();                          // disable interrupts for boot

#ifdef DEBUG
    suart_init();
    printf("Initializing YaLD...\n");
#endif

    initLEDs();
    initDIPs();

    //DmxAddress = 1;               // Just for debugging/testing with no dips / fixed address
    init_DMX_RX();
    get_dips();

    sei();                          // enable interrupts

    pwmout_init_output();

    // init timer for IRMP
    OCR2   =  (uint8_t) (((F_CPU / F_INTERRUPTS) / 8) - 1 + 0.5);  // Compare Register OCR2
    TCCR2  = (1 << WGM21) | (1 << CS21);                           // CTC Mode, prescaler = 8
    TIMSK  = 1 << OCIE2;                                           // enable timer2 interrupt
    irmp_init();

    millis_init();                  // changes timer config

    // init watchdog
    wdt_enable(WDTO_2S);

#ifdef DEBUG
    printf("Initialization complete.\n");
    suart_init();
#endif

    // Signalize on board that program is initialized
    blink();

    while(1) {
        get_dips();

        if (gGlobalState == EADDR) {
            blinkRed();
            _delay_ms(150);
            blinkRed();
            _delay_ms(800);
        }
        else if (gGlobalState == EADDR) {
            blinkRed();
            _delay_ms(800);
        }
        else if (gGlobalState == MODE_IR ||
                (gGlobalState == MODE_DMX && dmxIdleTicks >= (F_INTERRUPTS))) {

            // reset dmx idle counter to avoid overflow
            if (dmxIdleTicks > ((uint32_t)3 * (uint32_t)F_INTERRUPTS)) {
                dmxIdleTicks = ((uint32_t)3 * (uint32_t)F_INTERRUPTS);
            }

            ir_mode();
            pwmout_write_output(ir_raw);
        }
        else if (gGlobalState == MODE_DMX) {
            pwmout_write_output(DmxRxField);
        }

        // reset watchdog
        wdt_reset();
    }
}

// call ISR of IR module
ISR(TIMER2_COMP_vect) {
    dmxIdleTicks++;
    (void) irmp_ISR();
}
#else
int main(void) {
    wdt_disable();                  // disable watchdog for boot
    cli();                          // disable interrupts for boot

#ifdef DEBUG
    suart_init();
    printf("Initializing YaLD...\n");
#endif

    initLEDs();
    initDIPs();

    uart_simple_init();

    sei();                          // enable interrupts

    pwmout_init_output();

    // init watchdog
    wdt_enable(WDTO_2S);

#ifdef DEBUG
    printf("Initialization complete.\n");
    suart_init();
#endif

    // Signalize on board that program is initialized
    blink();

    while(1) {
        // Wait a little bit to slow down
        _delay_ms(1);

        pwmout_write_output(uart_simple_buffer);

        // reset watchdog
        wdt_reset();
    }
}

// call ISR of IR module
ISR(TIMER2_COMP_vect) {
}
#endif // #ifndef TARGET_UART_SIMPLE

static inline void initDIPs(void) {
    // init DIP ports as inputs
    DDRA |= 0x0; // all inputs
    DDRB &= ~((1 << DDB0) | (1 << DDB1));

    // activate pull-ups
    PORTA = 0xFF;
    PORTB |= ((1 << DDB0) | (1 << DDB1));
}
#ifdef __cplusplus
}
#endif

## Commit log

2014-10-26 initial commit, some work done, NOT ready for production!
    [YaLD.kicad_pcb, YaLD.sch, YaLD_amp.sch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]
2014-11-01 fixed RJ45 connectors + folder libs.pretty added
    RJ45 were on wrong side;
    [YaLD.kicad_pcb, YaLD.sch, YaLD_amp.sch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]
2014-11-20 refixed RJ45 - they have been on CORRECT side before!
    [YaLD.kicad_pcb]
2015-02-02 DMX plus/minus switched, GND airwire connected
    + nicer silk print (more readable)
    [YaLD.kicad_pcb, YaLD.sch, YalD_Connectors.sch]
2015-02-02 added ISP header orientation to silk
    [YaLD.kicad_pcb]
2015-02-03 added debug connector (software UART TX)
    [YaLD.kicad_pcb, YaLD.sch, YaLD_amp.sch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]
2015-07-04 meta stuff
    [DMX-Werte-PWM-neu.ods]
2016-08-25 old output added
    [YaLD-B_Cu.gbl, YaLD-B_Cu.gbr, YaLD-B_Mask.gbr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]
2016-08-25 changed outputs to 3.5mm pitch
    [YaLD.kicad_pcb, YaLD.sch, YaLD_amp.sch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]
2016-08-26 added silk texts, corrected bugs
    [YaLD.kicad_pcb]
2016-08-26 moved rj45
    [YaLD.kicad_pcb]
2016-08-26 added gerber files for YaLD v2.0
    [YaLD-B.Cu.gbl, YaLD-B.Mask.gbs, YaLD-B.Paste.gbp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]
2016-08-26 changed default state of 'use gerber extensions'
    [YaLD.kicad_pcb]
2019-08-28 version from old firmware repo + beginning of README
    [Assembler.obj]
2019-08-28 move header files into own directory
    + add gitignore to not track binaries
2020-06-27 add bill of materials for some formerly unmarked parts on the board
    (just for convience to not need to open kicad to build a pcb)
2020-06-27 simplify uart_simple algorithm
2020-06-28 add first start for esp32 firmware
2022-10-16 add current working state of bridge
2022-10-16 esp32 bridge: initialize `data` array to be empty on start
2022-10-16 esp bridge: improve int parsing / fix bug
    [main.cpp]
